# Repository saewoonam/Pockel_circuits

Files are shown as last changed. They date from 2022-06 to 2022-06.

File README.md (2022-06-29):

# Kicad projects for making the pockel cell controller
## List of parts
* circuit board -> DAC and digital IO:  DAC_pockel
* make front and back panel for the enclosure out of printed circuit board -> Front panel with DB9 connector: Pockel_front
* Enclosure from thorlabs: EED3011,  [link](https://www.thorlabs.com/newgrouppage9.cfm?objectgroup_ID=8681)

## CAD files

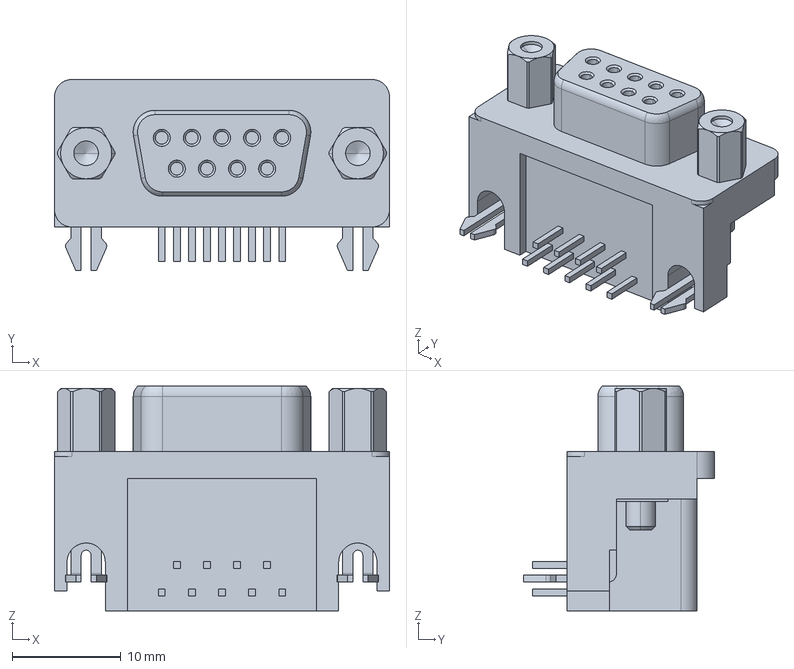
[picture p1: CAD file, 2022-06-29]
DAC_pockel/c-2301844-2-b-3d.stp
30.8 x 17.6 x 20.6 mm

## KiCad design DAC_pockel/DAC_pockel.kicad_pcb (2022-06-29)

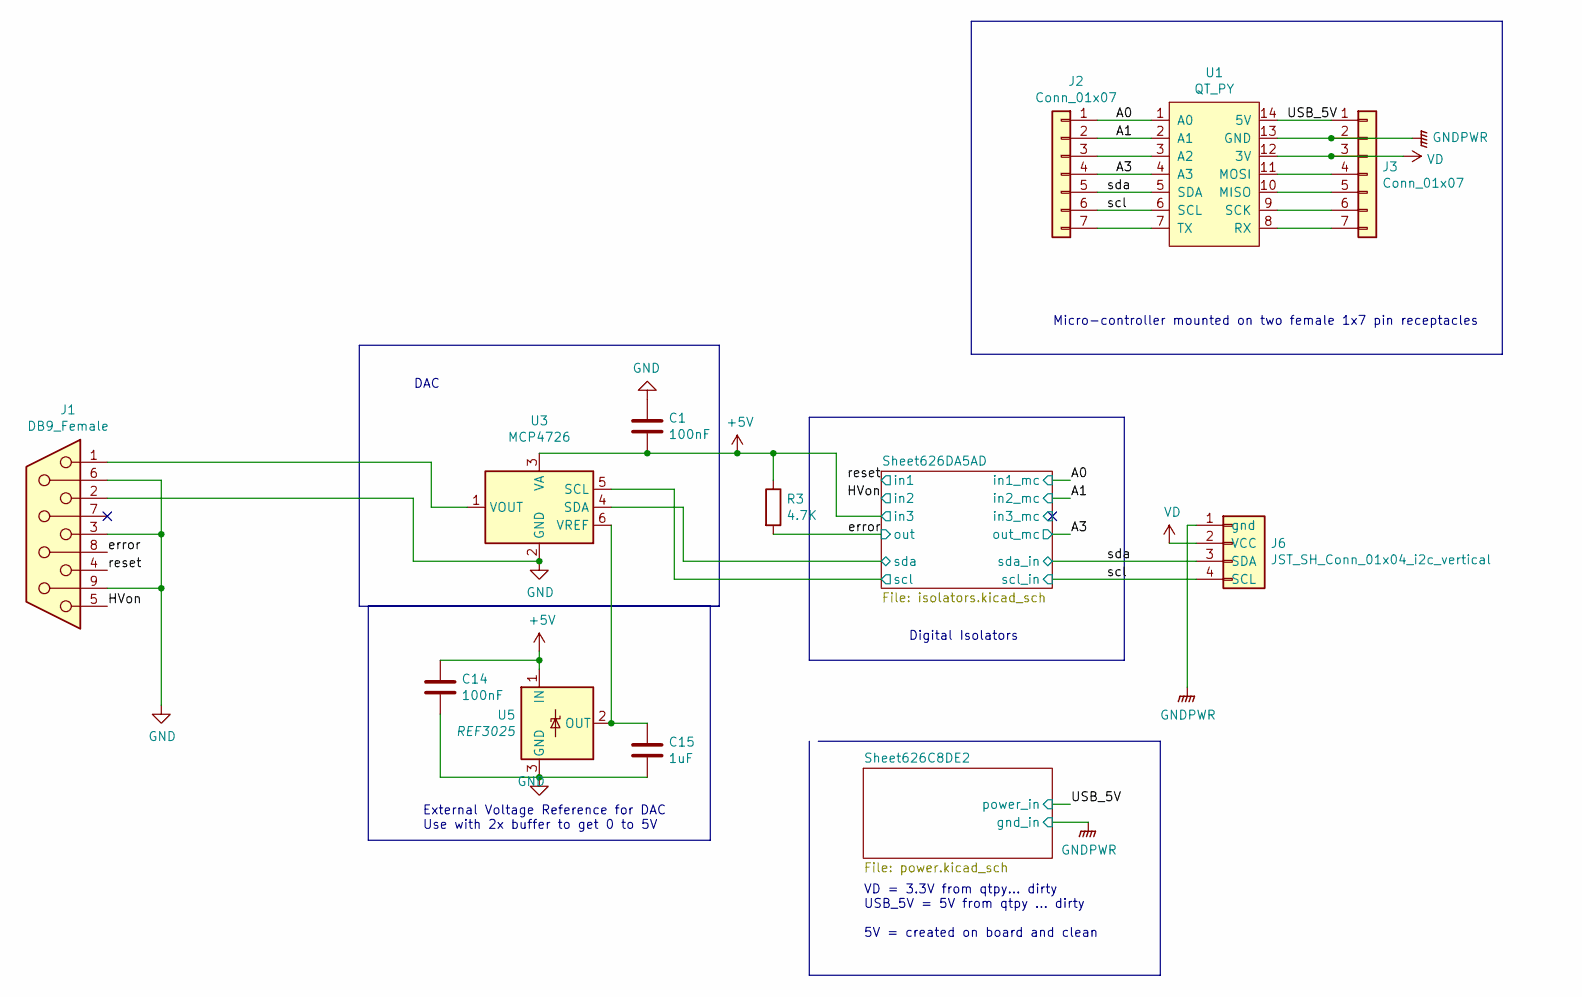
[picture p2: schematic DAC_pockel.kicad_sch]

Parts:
C1, C14: 100nF; C_0603_1608Metric_Pad1.05x0.95mm_HandSolder; MPN CC0603KRX7R9BB104; LCSC C14663
C15: 1uF; C_0603_1608Metric_Pad1.05x0.95mm_HandSolder; MPN CL10A105KB8NNNC; LCSC C15849
J1: DB9_Female; DSUB-TH_DS1037-09FNAKT74-0CC; MPN DS1037-09FNAKT74-0CC; LCSC C75749
J2, J3: Conn_01x07; PinSocket_1x07_P2.54mm_Vertical; LCSC C358721
J6: JST_SH_Conn_01x04_i2c_vertical; JST_SH_BM04B-SRSS-TB_1x04-1MP_P1.00mm_Vertical; MPN A1001WV-S-04PD01; LCSC C371602
R3: 4.7K; R_0603_1608Metric_Pad1.05x0.95mm_HandSolder; MPN 0603WAF4701T5E; LCSC C23162
U1: QT_PY
U3: MCP4726; SOT-23-6; MPN MCP4726A0T-E/CH; LCSC C191581
U5: REF3025; SOT-23

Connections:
+5V: C1.2, C14.1, R3.1, U3.3 (VA), U5.1 (IN); also elsewhere on the board
/A0: J2.1, U1.1 (A0); also elsewhere on the board
/A1: J2.2, U1.2 (A1); also elsewhere on the board
/A3: J2.4, U1.4 (A3); also elsewhere on the board
/HVon: J1.5; also elsewhere on the board
/Sheet626DA5AD/scl: U3.5 (SCL); also elsewhere on the board
/Sheet626DA5AD/sda: U3.4 (SDA); also elsewhere on the board
/USB_5V: J3.1, U1.14 (5V); also elsewhere on the board
/error: J1.8, R3.2; also elsewhere on the board
/reset: J1.4; also elsewhere on the board
/scl: J2.6, J6.4 (SCL), U1.6 (SCL); also elsewhere on the board
/sda: J2.5, J6.3 (SDA), U1.5 (SDA); also elsewhere on the board
GND: C1.1, C14.2, C15.2, J1.2, J1.3, J1.6, J1.9, U3.2 (GND), U5.3 (GND); also elsewhere on the board
GNDPWR: J3.2, J6.1 (gnd), U1.13 (GND); also elsewhere on the board
unnamed: C15.1, U3.6 (VREF), U5.2 (OUT)
unnamed: J1.1, U3.1 (VOUT)
unnamed: J2.3, U1.3 (A2)
unnamed: J2.7, U1.7 (TX)
unnamed: J3.4, U1.11 (MOSI)
unnamed: J3.5, U1.10 (MISO)
unnamed: J3.6, U1.9 (SCK)
unnamed: J3.7, U1.8 (RX)
VD: J3.3, J6.2 (VCC), U1.12 (3V); also elsewhere on the board

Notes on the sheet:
VD = 3.3V from qtpy… dirty USB_5V = 5V from qtpy … dirty 5V = created on board and clean
DAC
Digital Isolators
Micro-controller mounted on two female 1x7 pin receptacles
External Voltage Reference for DAC Use with 2x buffer to get 0 to 5V

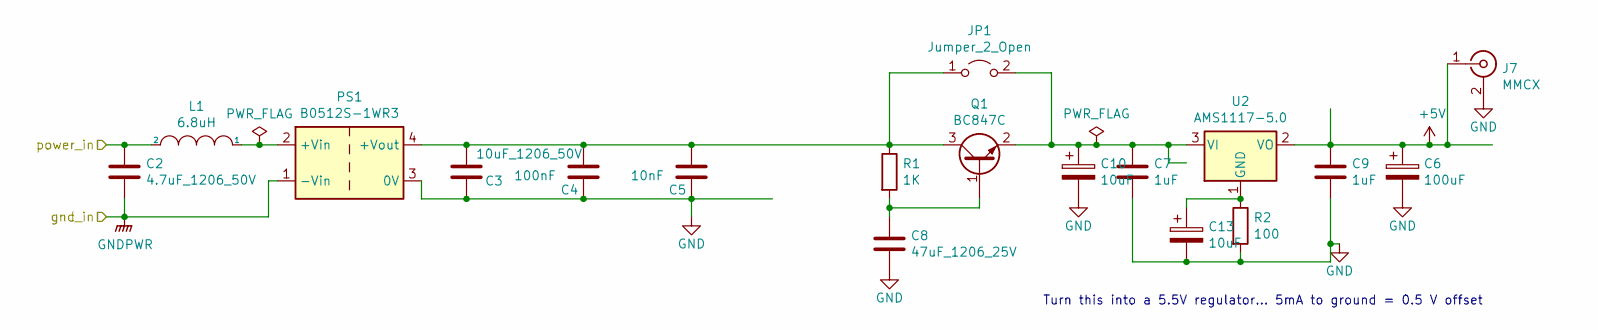
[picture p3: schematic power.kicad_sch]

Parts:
C2: 4.7uF_1206_50V; C_1206_3216Metric_Pad1.42x1.75mm_HandSolder; MPN 1206B475K500NT; LCSC C29823
C3: 10uF_1206_50V; C_1206_3216Metric_Pad1.42x1.75mm_HandSolder; MPN CL31A106KBHNNNE; LCSC C13585
C4: 100nF; C_0603_1608Metric_Pad1.05x0.95mm_HandSolder; MPN CC0603KRX7R9BB104; LCSC C14663
C5: 10nF; C_0603_1608Metric_Pad1.05x0.95mm_HandSolder; MPN 0603B103K500NT; LCSC C57112
C6: 100uF; CP_EIA-3528-12_Kemet-T; MPN GRM32ER61A107ME20L; LCSC C84455
C7, C9: 1uF; C_0603_1608Metric_Pad1.05x0.95mm_HandSolder; MPN CL10A105KB8NNNC; LCSC C15849
C8: 47uF_1206_25V; C_1206_3216Metric_Pad1.42x1.75mm_HandSolder; MPN GRM31CR61E476ME44L; LCSC C403725
C10, C13: 10uF; CP_EIA-3216-18_Kemet-A; MPN TAJA106K016RNJ; LCSC C7171
J7: MMCX; MMCX_JLC; MPN KH-MMCX-Z; LCSC C530664
JP1: Jumper_2_Open; SolderJumper-2_P1.3mm_Open_RoundedPad1.0x1.5mm
L1: 6.8uH; L_1210_3225Metric_Pad1.42x2.65mm_HandSolder; MPN NLCV32T-6R8M-PFR; LCSC C87559
PS1: B0512S-1WR3; Converter_DCDC_muRata_CRE1xxxxxx3C_THT; MPN B0512S-1WR3; LCSC C133158
Q1: BC847C; SOT-23; MPN BC847C,215; LCSC C8664
R1: 1K; R_0603_1608Metric_Pad1.05x0.95mm_HandSolder; MPN 0603WAF1001T5E; LCSC C21190
R2: 100; R_0603_1608Metric_Pad1.05x0.95mm_HandSolder; MPN 0603WAF1000T5E; LCSC C22775
U2: AMS1117-5.0; SOT-223-3_TabPin2

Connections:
+5V: C6.1, C9.1, J7.1 (In), U2.2 (VO); also elsewhere on the board
/USB_5V: C2.1, L1.2; also elsewhere on the board
GND: C3.2, C4.1, C5.1, C6.2, C7.2, C8.2, C9.2, C10.2, C13.2, J7.2 (Ext), PS1.3 (0V), R2.2; also elsewhere on the board
GNDPWR: C2.2, PS1.1 (-Vin); also elsewhere on the board
unnamed: C3.1, C4.2, C5.2, JP1.1 (A), PS1.4 (+Vout), Q1.3 (C), R1.1
unnamed: C8.1, Q1.1 (B), R1.2
unnamed: C7.1, C10.1, JP1.2 (B), Q1.2 (E), U2.3 (VI)
unnamed: C13.1, R2.1, U2.1 (GND)
unnamed: L1.1, PS1.2 (+Vin)

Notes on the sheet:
Turn this into a 5.5V regulator… 5mA to ground = 0.5 V offset

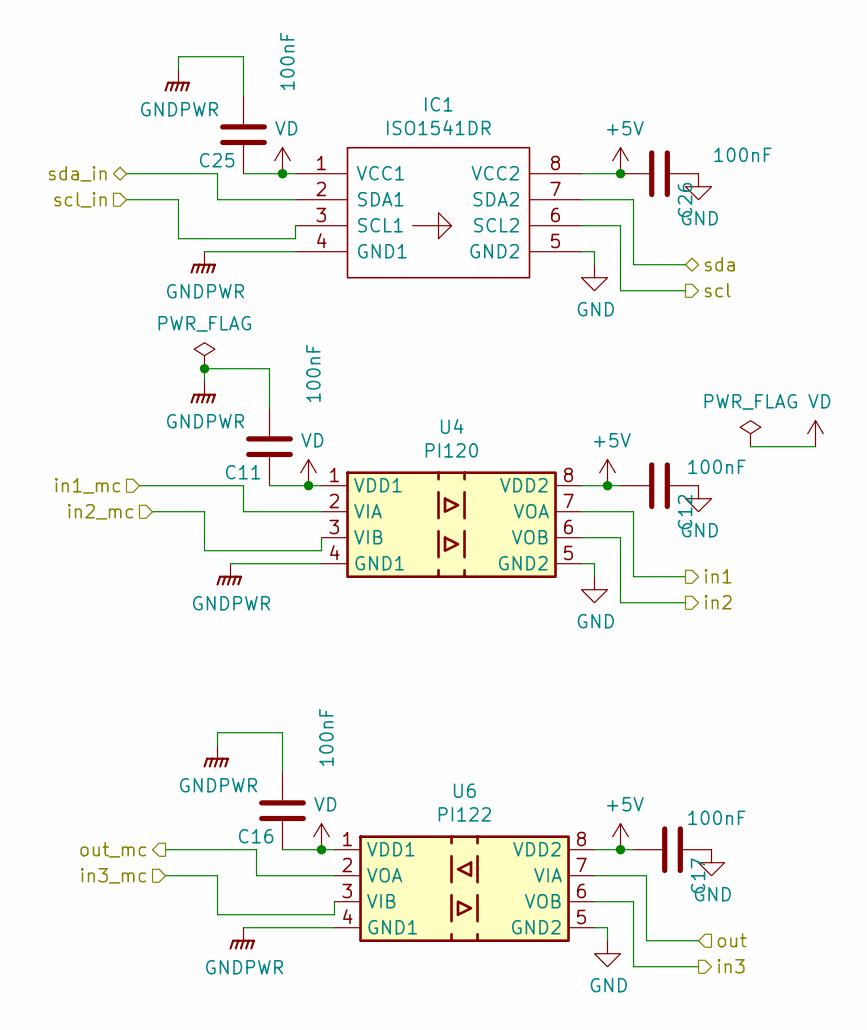
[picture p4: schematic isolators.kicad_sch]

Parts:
C11, C12, C16, C17, C25, C26: 100nF; C_0603_1608Metric_Pad1.05x0.95mm_HandSolder; MPN CC0603KRX7R9BB104; LCSC C14663
IC1: ISO1541DR; SOIC-8_3.9x4.9mm_P1.27mm; MPN ISO1541DR; LCSC C143028
U4: PI120; SOIC-8_3.9x4.9mm_P1.27mm; MPN π120U30; LCSC C471591
U6: PI122; SOIC-8_3.9x4.9mm_P1.27mm; MPN π122U31; LCSC C471590

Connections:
+5V: C12.2, C17.2, C26.2, IC1.8 (VCC2), U4.8 (VDD2), U6.6 (VOB), U6.8 (VDD2); also elsewhere on the board
/A0: U4.2 (VIA); also elsewhere on the board
/A1: U4.3 (VIB); also elsewhere on the board
/A3: U6.2 (VOA); also elsewhere on the board
/HVon: U4.6 (VOB); also elsewhere on the board
/Sheet626DA5AD/in3_mc: U6.3 (VIB)
/Sheet626DA5AD/scl: IC1.6 (SCL2); also elsewhere on the board
/Sheet626DA5AD/sda: IC1.7 (SDA2); also elsewhere on the board
/error: U6.7 (VIA); also elsewhere on the board
/reset: U4.7 (VOA); also elsewhere on the board
/scl: IC1.3 (SCL1); also elsewhere on the board
/sda: IC1.2 (SDA1); also elsewhere on the board
GND: C12.1, C17.1, C26.1, IC1.5 (GND2), U4.5 (GND2), U6.5 (GND2); also elsewhere on the board
GNDPWR: C11.2, C16.2, C25.2, IC1.4 (GND1), U4.4 (GND1), U6.4 (GND1); also elsewhere on the board
VD: C11.1, C16.1, C25.1, IC1.1 (VCC1), U4.1 (VDD1), U6.1 (VDD1); also elsewhere on the board

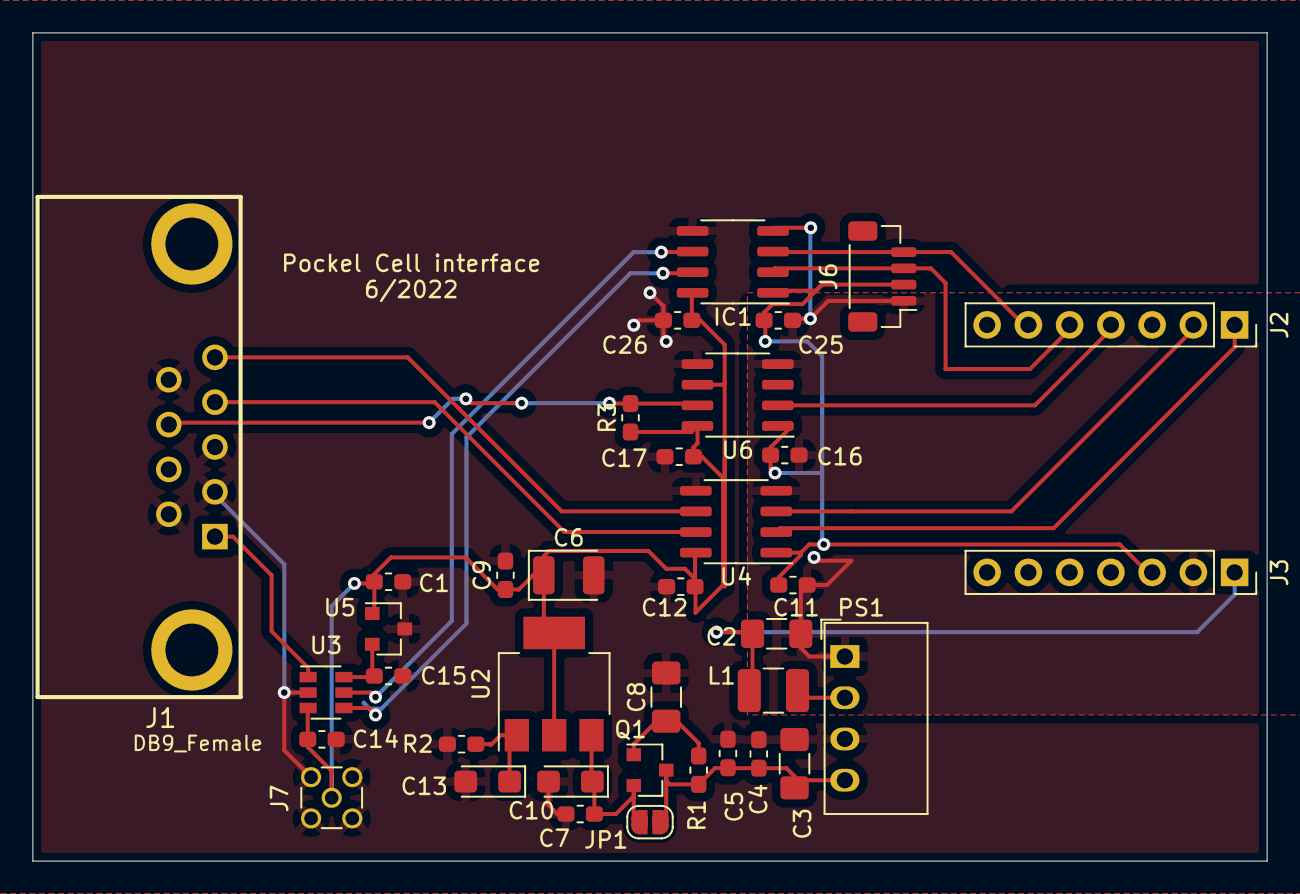
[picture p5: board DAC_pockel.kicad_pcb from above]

Board: 2 copper layers, 76.0 x 51.0 mm, 37 parts (0 on the bottom side), 22 nets.
